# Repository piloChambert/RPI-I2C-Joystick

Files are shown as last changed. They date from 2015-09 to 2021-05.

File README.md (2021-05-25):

# RPI-I2C-Joystick

I2C Arduino based joystick for Raspberry Pi in order to be used with [RetroPie](https://github.com/RetroPie/RetroPie-Setup).
The Arduino is also used to control audio volume and power management (switch the Raspberry Pi on and off).

## Aruino

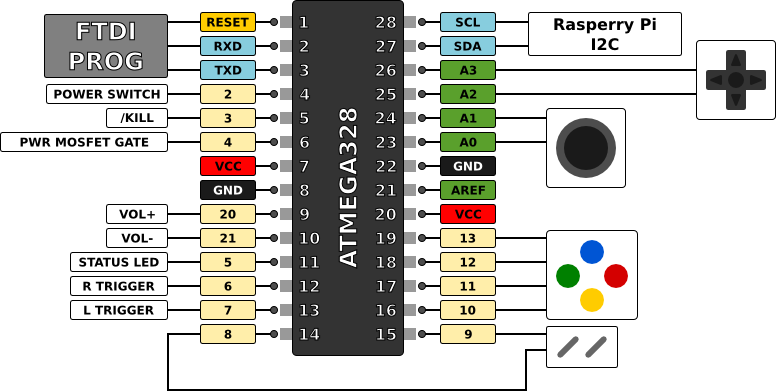
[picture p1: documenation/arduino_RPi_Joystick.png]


- The arduino (an ATMega328 running with its internal 8Mhz clock) is used to control the Raspberry Pi. It's used to read joystick buttons and analog axis. 
- The [board](https://github.com/piloChambert/RPI-I2C-Joystick/board) directory contains the schematic (and pcb), compatible with raspberry Pi GPIO. THIS IS A WORK IN PROGRESS!!! By now it's tested on a breadboard.
- The [i2c_gamepad](https://github.com/piloChambert/RPI-I2C-Joystick/i2c_gamepad) directory contains the actual arduino code. 

### hardware

The [hardware](https://github.com/piloChambert/RPI-I2C-Joystick/tree/master/hardware) directory contains the definition for the ATMega328 without quartz configuration (and PINB6 and PINB7 enable).

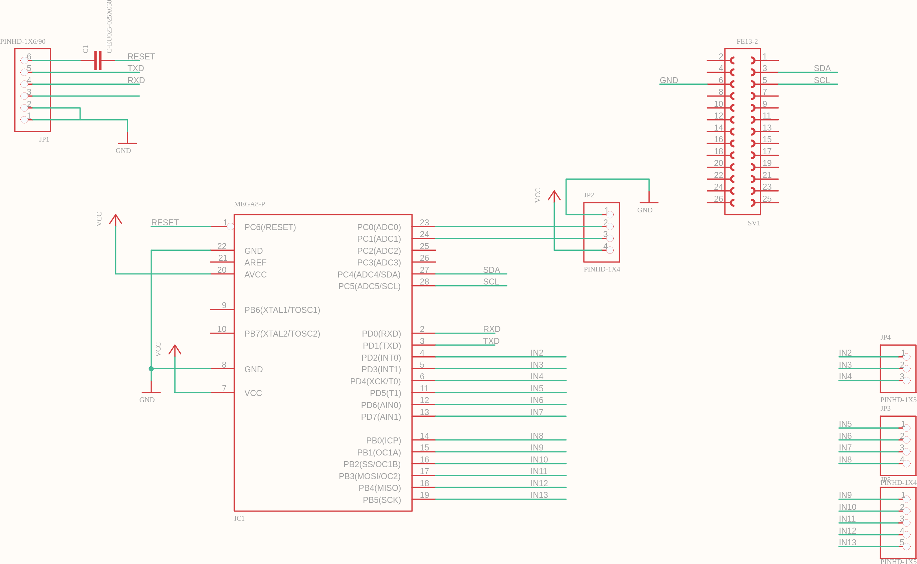
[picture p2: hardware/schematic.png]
schematic

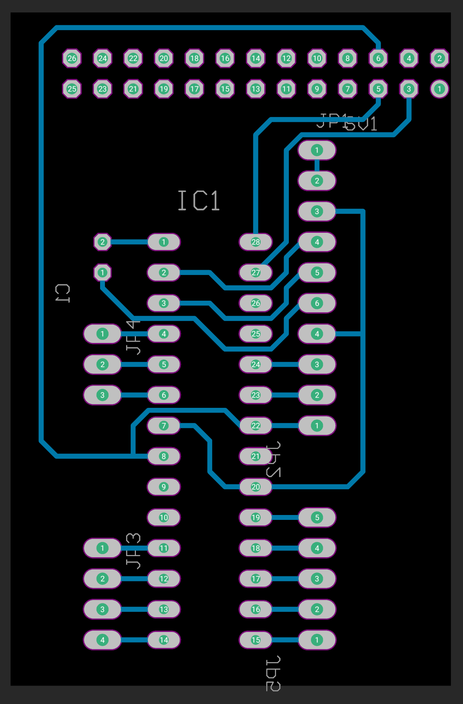
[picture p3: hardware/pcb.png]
pcb


## Raspberry Pi

### power

In order to know when the raspberry pi has been shutdown, the gpio-poweroff overlay is used. This is the /kill signal going to the arduino (HIGH when the raspberry pi is halted).

In /boot/config.txt:
```
dtoverlay=gpio-poweroff,gpiopin=4,active_low="y"
```

### joystick

The [driver](https://github.com/piloChambert/RPI-I2C-Joystick/driver) directory contains the code of the user space uinput driver for the arduino I2C joystick.

### Display Configuration

I use a 4.3" 480x272 TFT display using composite video (maybe the worst quality possible). It would be better to use a DPI interface (with the GPIO, an HDMI to DPI converter, or a DSI to DPI converter).

Here's my video and overscan settings in `/boot/config.txt`
```
disable_overscan=1

overscan_left=34
overscan_right=20
overscan_top=16
overscan_bottom=20
overscan_scale=1

# set the frame buffer to match the tft resolution
framebuffer_width=480
framebuffer_height=272
framebuffer_depth=24

# use PAL, it seems way better than NTSC!!
sdtv_mode=2

# 16:9 aspect
sdtv_aspect=3

```

In order to setup the overscan settings, I used https://github.com/popcornmix/set_overscan, and then tweaked the values by hand.

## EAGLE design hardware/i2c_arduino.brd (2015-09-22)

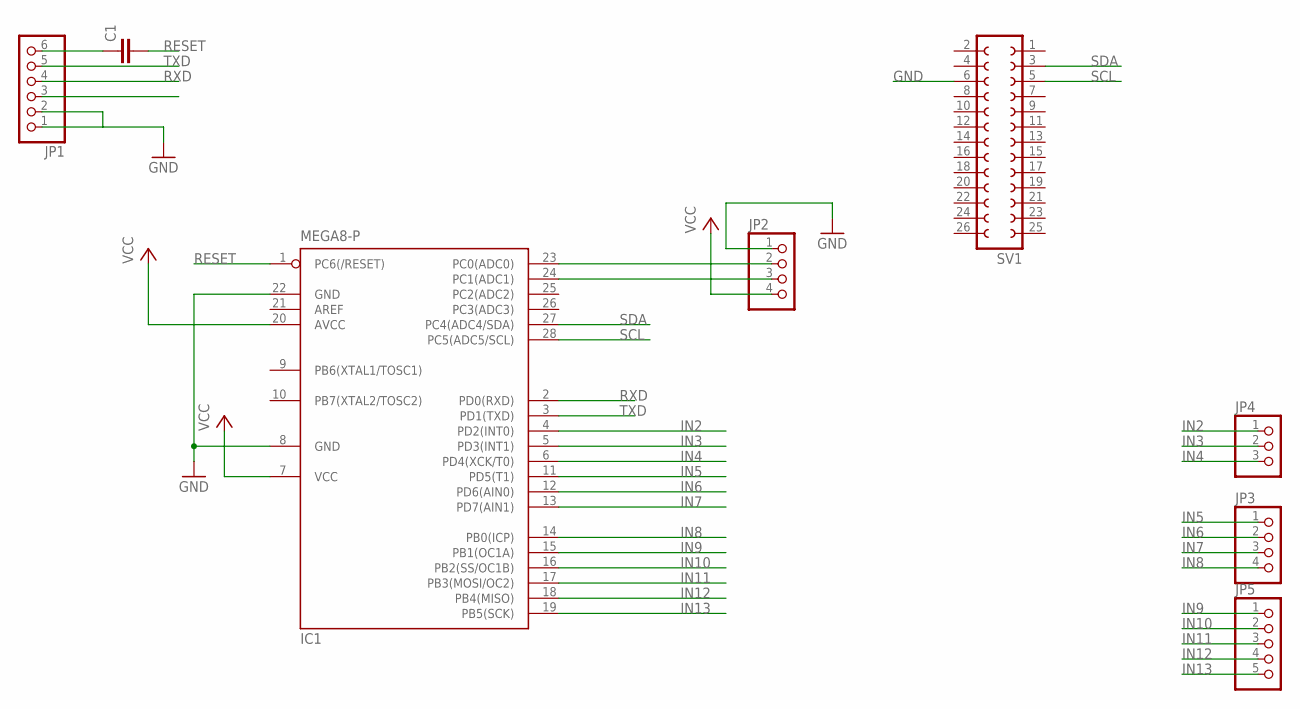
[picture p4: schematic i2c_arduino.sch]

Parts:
C1: C-EU025-025X050; C025-025X050
IC1: MEGA8-P; DIL28-3
JP1: PINHD-1X6/90; 1X06/90
JP2, JP3: PINHD-1X4; 1X04
JP4: PINHD-1X3; 1X03
JP5: PINHD-1X5; 1X05
SV1: FE13-2

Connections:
GND: IC1.8 (GND), IC1.22 (GND), JP1.1, JP1.2, JP2.1, SV1.6
IN2: IC1.4 (PD2(INT0)), JP4.1
IN3: IC1.5 (PD3(INT1)), JP4.2
IN4: IC1.6 (PD4(XCK/T0)), JP4.3
IN5: IC1.11 (PD5(T1)), JP3.1
IN6: IC1.12 (PD6(AIN0)), JP3.2
IN7: IC1.13 (PD7(AIN1)), JP3.3
IN8: IC1.14 (PB0(ICP)), JP3.4
IN9: IC1.15 (PB1(OC1A)), JP5.1
IN10: IC1.16 (PB2(SS/OC1B)), JP5.2
IN11: IC1.17 (PB3(MOSI/OC2)), JP5.3
IN12: IC1.18 (PB4(MISO)), JP5.4
IN13: IC1.19 (PB5(SCK)), JP5.5
unnamed: C1.1, JP1.6
unnamed: IC1.23 (PC0(ADC0)), JP2.2
unnamed: IC1.24 (PC1(ADC1)), JP2.3
RESET: C1.2, IC1.1 (PC6(/RESET))
RXD: IC1.2 (PD0(RXD)), JP1.4
SCL: IC1.28 (PC5(ADC5/SCL)), SV1.5
SDA: IC1.27 (PC4(ADC4/SDA)), SV1.3
TXD: IC1.3 (PD1(TXD)), JP1.5
VCC: IC1.7 (VCC), IC1.20 (AVCC), JP1.3, JP2.4

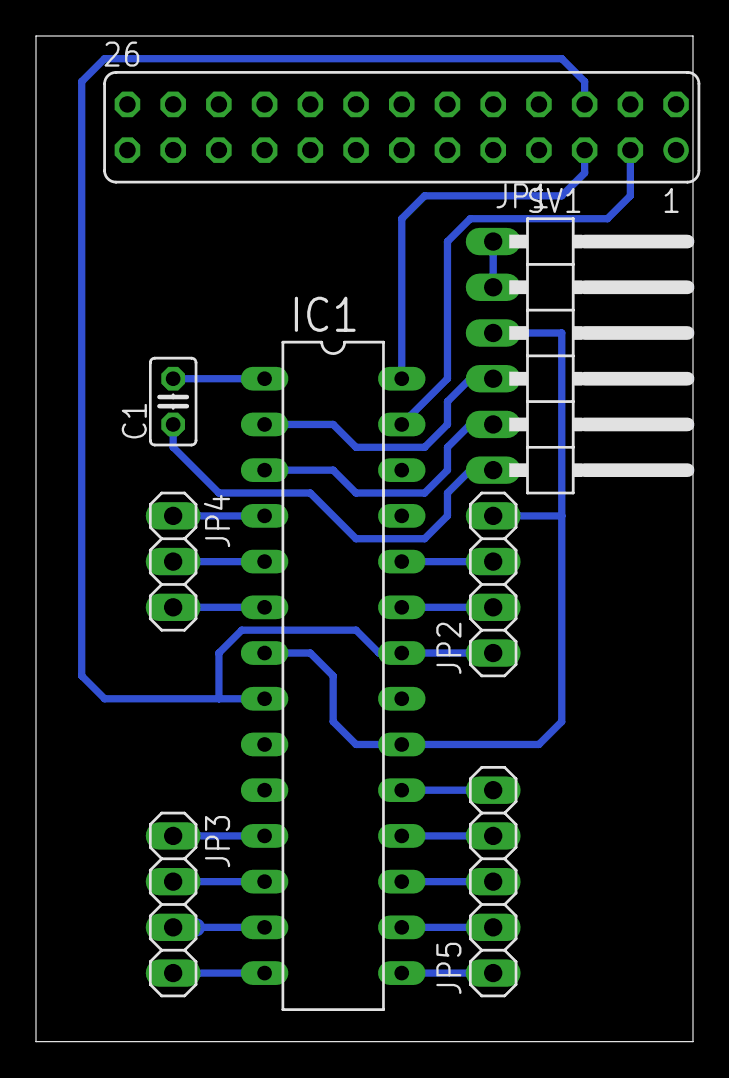
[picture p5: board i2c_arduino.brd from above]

Board: 2 copper layers, 36.5 x 55.9 mm, 8 parts (0 on the bottom side), 22 nets.

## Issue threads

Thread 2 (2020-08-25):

Question about I2C driver for this joystick

AlexShi23, 2020-08-25:
Hi, I wanted to assembly joystick according to your project. I'm having a problem with the driver. It compiled, but the device is still not available. Maybe I did something wrong, help me figure it out please.

piloChambert, 2020-08-26:
Hi!
Of course I can help :)

Did you check that the I2C is working on the raspberry?
https://learn.adafruit.com/adafruits-raspberry-pi-lesson-4-gpio-setup/configuring-i2c : with i2cdetect you should see the arduino at address 0x18.

It's an old project, so there might be some bugs (and I never finish the power switch stuff).

AlexShi23, 2020-08-26:
OK, device in Retropie appears at 0x18. Next, I copy the folder with the driver files to the Raspberry / home folder, then the make command and then I don’t know what to do.

piloChambert, 2020-08-26:
The program run i2c-joystick-driver should poll the arduino for input event, and then to a an emulated input device.
So when you run it, a new joystick should appear on your system.
To start it in background mode just run `./i2c-joystick-driver &` from the source directory.

But I think it should be used as a daemon to start it automatically with the system.

Which distribution are you using?
You can try to run `jstest /dev/input/js0` while i2c-joystick-driver to see if the different buttons are working.

AlexShi23, 2020-09-02:
Hi
I added ./i2c-joystick-driver & to startup and the system detected one game device. I use Retropie 4.5. But the joystick buttons are not pressed. The I2C device is discovered at address 0x18, but the device at address 0x68 is also detected. jstest /dev/input/js0 does not detect keystrokes. System shutdown often occur spontaneously. If turn off the Atmega328 or change the address, spontaneous shutdown disappears.
I am not good at programming code, so all hope is for your advice.

piloChambert, 2020-09-03:
Hi!
When you said "but the device at address 0x68 is also detected", is it still detected when the arduino is powered off? (it might be another I2C device inside your computer at address 0x68).

And how did you wire the button on the arduino?

To prevent the system shutdown, you can try to change ligne 261 in i2c_gamepad.ino to
`stateFunction = runState;`

and change ligne 157 to:
`if(0) {`
(instead of `if(powerSwitchHasBeenReleased && powerSwitch.state == LOW && millis() - powerSwitchPressTime > 4000) {`)

AlexShi23, 2020-09-03:
I changed lines 157 and 261 as You recommended and the buttons worked. I will move on. Thanks for answers!

piloChambert, 2020-09-05:
Great! :)
The arduino wasn't in the right mode (it was in standby mode), and that's why it wasn't working as expected. I might change that and push a fix.

I'm wondering in what kind of project you are using it? Is it for a portable pi console?

AlexShi23, 2020-09-06:
Yes. Raspberry CM3 based portable console. LCD 4.3" DPI mode.

AlexShi23, 2020-09-08:
Hi
I don’t understand how the hat is connected. How to convert a hat from analog to digital buttons? I am not using volume control and these pins are free.

piloChambert, 2020-09-09:
Seems like a very interesting project :)
Did you make a custom PCB for the compute module? That's what I wanted to do, but I never took time to finish my prototype back then! DPI screen is a really nice feature! Will you make it a public project?

For the "analog" hat wiring, I was using a voltage divider (0, 2.5v, 5v) for hat axis. But I just push a commit which should allow you to use digital pin instead for the hat (pin 20, 21, 16, 17, look lines 58 to 61) and disable volume control (and power management too).

At the top of the ino file I added compilation  configuration:
`#define USE_VOLUME_BUTTON 0`
`#define USE_ANALOG_HAT 0`
`#define USE_POWER_FUNCTION 0`

You can leave all of them to 0 in your case.

AlexShi23, 2020-09-09:
Hi
Thanks for your responsiveness.
At the moment this is a prototyping board. From the interesting will be the use of the ALC5628 DAC. I've spent some time studying it. DPI mode will occupy the entire GPIO Bank0.
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

This will be a public project, but maybe I'll be making kits for sale.

AlexShi23, 2020-09-09:
Up, down, left, right buttons are not defined by the system. I think the reason is in the driver, there they are not declared anywhere.

piloChambert, 2020-09-10:
Hey!
You're welcome! I wrote this I2C joystick driver a while ago, and never really finish the project... so I'm happy to know it could be useful to someone else :)
A DAC for audio is a really nice feature! I wanted to use a TDA1543 (hard to find the I2S one).

And you were right, the dpad event wasn't handle in the driver code! I just fixed it, and a push a new commit.
I couldn't test it, so I hope it works.
In linux DPad can be handle as button events or analog axis (xbox 360 gamepad for example generate axis event), so I added a compile option in i2c-joystick-driver.c (line 12, `#define USE_ANALOG_DPAD 0`) to use either one mode or the other.
Set it to 0 and it will generate button event (which I think should be fine for retropie)

AlexShi23, 2020-09-10:
Hi
The file JoystickDevice.c also needed to be fixed. I did it myself. Everything is working! Thanks! I'll keep you up to date.

piloChambert, 2020-09-11:
Oh, did I forgot to register DPAD_BTN_*?
`ret |= ioctl(fd, UI_SET_KEYBIT, BTN_DPAD_UP);`
`ret |= ioctl(fd, UI_SET_KEYBIT, BTN_DPAD_DOWN);`
`ret |= ioctl(fd, UI_SET_KEYBIT, BTN_DPAD_LEFT);`
`ret |= ioctl(fd, UI_SET_KEYBIT, BTN_DPAD_RIGHT);`

If you want to make a merge request I'll accept it ;) (or I can fix it with a commit).

I'd love to be updated on your project! :) Thank you!

crom4, 2020-11-18:
Hi! Thanks for the help! I never wrote but I was trying to finish this project but i had the same doubts as the other user. I'll prove what you said.

What and how is the use of the pwr mosfet gate pin? Thank you!

piloChambert, 2020-11-19:
Hey!
You're welcome! I should provide more information for the arduino code.

The power mosfet pin should be used to power on and off the raspberry pi. I can't remember if I tested or implemented it yet.
I wanted to make the arduino able to manage raspberry pi power state, but there may be other way of doing this now?

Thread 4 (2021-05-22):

Hardware Images

konsumer, 2021-05-22:
Great project!

I like to see schematic/PCB without loading it up into a viewer. It can be really nice just right in the README file. If you are interested, I can PR for these in README:

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

piloChambert, 2021-05-23:
Thank you!

And yes you can make a PR, and I'll merge it.
I didn't know about altium, it's a nice and handy tool!

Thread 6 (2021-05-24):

Question: serial comm

konsumer, 2021-05-24:
Hi,
I like the design of the board, but I was thinking I could free up 2 more IO pins from arduino if I used the RX/TX instead of i2c to talk to pi, and this would also allow me to write the "firmware" from pi, and allow other styles of firmware like [firmata](https://www.arduino.cc/en/reference/firmata) (keep logic in the driver, and the Arduino is just used for it's GPIO.) Do you have any opinions on this? Am I wrong about this as an alternative?

konsumer, 2021-05-24:
It seems like it might also allow something like [this](https://github.com/mcgurk/Linux-Arduino-Serial-Joystick).

piloChambert, 2021-05-25:
Using the serial port is actually a very smart idea !
I feel stupid to not thought about it when doing the I2C.

The Linux-Arduino-Serial-Joystick project seems to do this?

konsumer, 2021-05-25:
I was originally looking for i2c, and it helped my find this project. I think both are good, depending on what you're doing (if I were doing a bunch of i2c, I could have them share the 2 pins, saving the serial for something else.) Also, I'm not sure if serial timing is ok without a XTAL. I'll do some tests and report back. It may make sense to have both options.

konsumer, 2021-05-25:
I made [this](https://github.com/notnullgames/arduinojoystick) for initial ideas, but I still need to do a lot of testing.

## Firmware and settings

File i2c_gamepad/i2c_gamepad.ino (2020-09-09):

#include <Wire.h>
#include <avr/sleep.h>

// ------------------------------------------
// Options
// ------------------------------------------
#define USE_VOLUME_BUTTON 0
#define USE_ANALOG_HAT 0 // USE_VOLUME_BUTTON should be 0 in order to use USE_ANALOG_HAT = 0
#define USE_POWER_FUNCTION 0

// ------------------------------------------
// Configuration
// ------------------------------------------
#define I2C_ADDRESS 0x18
#define SWITCH_DEBOUNCE_TIME 50 // ms
#define ANALOG_PIN_X 0
#define ANALOG_PIN_Y 1
#define HAT_PIN_X 2
#define HAT_PIN_Y 3
#define POWER_LED_PIN 5
#define POWER_SWITCH_PIN 2
#define POWER_MOSFET_GATE 4
#define PI_KILL_PIN 3

// switch type definition
#define BTN_A           0x00
#define BTN_B           0x01
#define BTN_X           0x02
#define BTN_Y           0x03
#define BTN_LT          0x04
#define BTN_RT          0x05
#define BTN_START       0x06
#define BTN_SELECT      0x07
#define BTN_UP          0x08
#define BTN_DOWN        0x09
#define BTN_LEFT        0x0A
#define BTN_RIGHT       0x0B
#define BTN_DUMMY       0xFF

struct InputSwitch {
  unsigned char pin;
  unsigned char state;
  unsigned long time;
  unsigned char code;
};

// the 8 switches 
InputSwitch switches[] = {
  {13, HIGH, 0, BTN_A},
  {12, HIGH, 0, BTN_B},
  {11, HIGH, 0, BTN_X},
  {10, HIGH, 0, BTN_Y},
  {7, HIGH, 0, BTN_LT},
  {6, HIGH, 0, BTN_RT},
  {8, HIGH, 0, BTN_START},
  {9, HIGH, 0, BTN_SELECT},
#if USE_ANALOG_HAT == 0
  {20, HIGH, 0, BTN_UP},
  {21, HIGH, 0, BTN_DOWN},
  {16, HIGH, 0, BTN_LEFT},
  {17, HIGH, 0, BTN_RIGHT},
#endif
};

// force analog hat if using volume button
#if USE_VOLUME_BUTTON == 1
#define USE_ANALOG_HAT 1
#endif

// return true if switch state has changed!
bool updateSwitch(struct InputSwitch *sw) {
  int newState = digitalRead(sw->pin);

  if(newState != sw->state && millis() - sw->time > SWITCH_DEBOUNCE_TIME) {
    // change state!
    sw->state = newState;

    // record last update
    sw->time = millis();
    
    return true;
  }

  // else 
  return false;
}

// I2C data definition
struct I2CJoystickStatus {
  uint16_t buttons; // button status
  uint8_t axis0; // first axis
  uint8_t axis1; // second axis
  uint8_t powerDownRequest; // when true, request the pi to shutdown
  uint8_t audioVolume;
};

I2CJoystickStatus joystickStatus;

InputSwitch powerSwitch = {POWER_SWITCH_PIN, HIGH, 0, 0};
unsigned long powerSwitchPressTime = 0;
bool powerSwitchHasBeenReleased = true; // a flag used to know if the power switch has been released since last state change

unsigned long ledBlinkTimer = 0;
int powerLedStatus = LOW;

#if USE_VOLUME_BUTTON == 1
InputSwitch volPlusSwitch = {20, HIGH, 0, BTN_DUMMY};
InputSwitch volMinusSwitch = {21, HIGH, 0, BTN_DUMMY};
#endif

void (*stateFunction)(void);
unsigned long wakeUpTime = 0;

void startupState() {
  // blink led
  if(millis() - ledBlinkTimer > 500) {
    powerLedStatus = powerLedStatus == HIGH ? LOW : HIGH;
    
    digitalWrite(POWER_LED_PIN, powerLedStatus);
    ledBlinkTimer = millis();
  }
  
  // update power switch
  if(updateSwitch(&powerSwitch)) {
    if(powerSwitch.state == LOW) {
      Serial.println("Pressed");
      powerSwitchPressTime = millis();
    } else {
      powerSwitchHasBeenReleased = true;
    }
  }

  if(powerSwitch.state == LOW) {
    // reset sleep timer
    wakeUpTime = millis();

    // if pressing power for more the 3s, change state
    if(millis() - powerSwitchPressTime > 3000) {
      // go to run state
      stateFunction = runState;

      // reset release flag
      powerSwitchHasBeenReleased = false;
    
      // led is on
      powerLedStatus = HIGH;
      digitalWrite(POWER_LED_PIN, powerLedStatus);

      // power the pi
      digitalWrite(POWER_MOSFET_GATE, LOW);      

      Serial.println("Starting up the pi!");
    }
  }

  // if still in this state after 5s, go to sleep
  if(millis() - wakeUpTime > 5000 && powerSwitch.state == HIGH) {
    Serial.println("Go to sleep");
    delay(1000);
    sleepNow();
  }
}

void runState() {
#if USE_POWER_FUNCTION == 1
  // update power switch
  if(updateSwitch(&powerSwitch)) {
    if(powerSwitch.state == LOW) {
      Serial.println("Pressed");
      powerSwitchPressTime = millis();
    } else {
      powerSwitchHasBeenReleased = true;
    }
  }

  // if the switch has been released since we are in this state
  // if it's pressed and pressed for more than 4s, then change state
  if(powerSwitchHasBeenReleased && powerSwitch.state == LOW && millis() - powerSwitchPressTime > 4000) {
    // go to halt state
    stateFunction = haltState;

    // reset power switch timer to highest value
    powerSwitchHasBeenReleased = false;

    // stoping the pi
    joystickStatus.powerDownRequest = 1;

    Serial.println("Stoping the pi!");
  }
#endif

  // update switch etc
  scanAnalog();
  scanInput();
}

void haltState() {
  // blink status led
  if(millis() - ledBlinkTimer > 100) {
    if(powerLedStatus == LOW) {
      powerLedStatus = HIGH;
    } else {
      powerLedStatus = LOW;
    }

    digitalWrite(POWER_LED_PIN, powerLedStatus);
    ledBlinkTimer = millis();
  }  

  // wait for pi kill signal
  if(digitalRead(PI_KILL_PIN) == LOW) {
    // shut down the power
    digitalWrite(POWER_MOSFET_GATE, HIGH);

    // go back to start state
    stateFunction = startupState;
  }
}

void pinInterrupt(void) {
  detachInterrupt(0);
}

void sleepNow() {
  // Set sleep enable (SE) bit:
  sleep_enable();
  
  attachInterrupt(0, pinInterrupt, LOW);
  
  // Choose our preferred sleep mode:
  set_sleep_mode(SLEEP_MODE_PWR_DOWN);

  // turn led off
  digitalWrite(POWER_LED_PIN, LOW);
 
  // Put the device to sleep:
  sleep_mode();
 
  // Upon waking up, sketch continues from this point.
  sleep_disable();

  wakeUpTime = millis();
  delay(1000);
  Serial.println("Awake!!");
}

void setup()
{
  Wire.begin(I2C_ADDRESS);      // join i2c bus 
  Wire.onRequest(requestEvent); // register event

  // prints title with ending line break
  Serial.begin(9600);
  while (!Serial) {
    ; // wait for serial port to connect. Needed for Leonardo only
  }
  Serial.println("I2C Gamepad controller");

  // default status
  joystickStatus.buttons = 0;
  joystickStatus.axis0 = 127;
  joystickStatus.axis1 = 127;
  joystickStatus.powerDownRequest = 0;
  joystickStatus.audioVolume = 100;
  
  // pin configuration
  for(int i = 0; i < sizeof(switches) / sizeof(InputSwitch); i++) {
    pinMode(switches[i].pin, INPUT_PULLUP);
  }

  pinMode(POWER_LED_PIN, OUTPUT);
  digitalWrite(POWER_LED_PIN, HIGH);

  pinMode(POWER_SWITCH_PIN, INPUT_PULLUP);
  pinMode(PI_KILL_PIN, INPUT_PULLUP);

#if USE_VOLUME_BUTTON == 1
  pinMode(volPlusSwitch.pin, INPUT_PULLUP);
  pinMode(volMinusSwitch.pin, INPUT_PULLUP);
#endif

  pinMode(POWER_MOSFET_GATE, OUTPUT);

  // switch to startup state
#if USE_POWER_FUNCTION == 1
  stateFunction = startupState;
#else
  stateFunction = runState;
#endif

  // turn led on
  powerLedStatus = HIGH;
  ledBlinkTimer = millis();
  digitalWrite(POWER_LED_PIN, powerLedStatus);
}

void scanInput() {
  for(int i = 0; i < sizeof(switches) / sizeof(InputSwitch); i++) {
    if(updateSwitch(&switches[i])) {
      if(switches[i].state == HIGH) // button released
        joystickStatus.buttons &= ~(1 << switches[i].code);
      else // button pressed
        joystickStatus.buttons |= (1 << switches[i].code);
    }
  }

  static uint16_t oldButtons = 0;
  if(joystickStatus.buttons != oldButtons) {
    Serial.println(joystickStatus.buttons);
    oldButtons = joystickStatus.buttons;
  }

#if USE_VOLUME_BUTTON == 1
  // volume
  if(updateSwitch(&volPlusSwitch) && volPlusSwitch.state == LOW) {
    joystickStatus.audioVolume = min(joystickStatus.audioVolume + 5, 100); 
  }

  if(updateSwitch(&volMinusSwitch) && volMinusSwitch.state == LOW) {
    joystickStatus.audioVolume = max(joystickStatus.audioVolume - 5, 0); 
  }
#endif
}

void scanAnalog() {
  // read analog stick values
  int x = analogRead(ANALOG_PIN_X);
  int y = analogRead(ANALOG_PIN_Y);

  // translate into a valid range
  x = min(max(((x - 240) / 10), 0) << 2, 255);
  y = min(max(((y - 200) / 10), 0) << 2, 255);

  // store them in the I2C data
  joystickStatus.axis0 = x;
  joystickStatus.axis1 = y;

  // read hat values
#if USE_ANALOG_HAT == 1
  int hatx = analogRead(HAT_PIN_X);
  if(hatx > 300 && hatx < 400)
    joystickStatus.buttons |= (1 << BTN_LEFT);
  else
    joystickStatus.buttons &= ~(1 << BTN_LEFT);

  if(hatx > 950)
    joystickStatus.buttons |= (1 << BTN_RIGHT);
  else
    joystickStatus.buttons &= ~(1 << BTN_RIGHT);
  
  int haty = analogRead(HAT_PIN_Y);
  if(haty > 300 && haty < 400)
    joystickStatus.buttons |= (1 << BTN_UP);
  else
    joystickStatus.buttons &= ~(1 << BTN_UP);

  if(haty > 950)
    joystickStatus.buttons |= (1 << BTN_DOWN);
  else
    joystickStatus.buttons &= ~(1 << BTN_DOWN);

  /*
  Serial.print("x : "); Serial.print(hatx);
  Serial.print("y : "); Serial.print(haty);
  Serial.println("");*/
#endif
}

void loop() {
  // execute state function
  stateFunction();
  delay(10);
}

// function that executes whenever data is requested by master
// this function is registered as an event, see setup()
void requestEvent() {
  Wire.write((char *)&joystickStatus, sizeof(I2CJoystickStatus)); 
}

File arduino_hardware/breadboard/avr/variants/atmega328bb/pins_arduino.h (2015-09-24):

/*
  pins_arduino.h - Pin definition functions for Arduino
  Part of Arduino - http://www.arduino.cc/

  Copyright (c) 2007 David A. Mellis

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
  $Id: wiring.h 249 2007-02-03 16:52:51Z mellis $
*/

#ifndef Pins_Arduino_h
#define Pins_Arduino_h

#include <avr/pgmspace.h>

#define NUM_DIGITAL_PINS            22
#define NUM_ANALOG_INPUTS           6
#define analogInputToDigitalPin(p)  ((p < 6) ? (p) + 14 : -1)

#if defined(__AVR_ATmega8__)
#define digitalPinHasPWM(p)         ((p) == 9 || (p) == 10 || (p) == 11)
#else
#define digitalPinHasPWM(p)         ((p) == 3 || (p) == 5 || (p) == 6 || (p) == 9 || (p) == 10 || (p) == 11)
#endif

static const uint8_t SS   = 10;
static const uint8_t MOSI = 11;
static const uint8_t MISO = 12;
static const uint8_t SCK  = 13;

static const uint8_t SDA = 18;
static const uint8_t SCL = 19;
#define LED_BUILTIN 13

static const uint8_t A0 = 14;
static const uint8_t A1 = 15;
static const uint8_t A2 = 16;
static const uint8_t A3 = 17;
static const uint8_t A4 = 18;
static const uint8_t A5 = 19;
static const uint8_t A6 = 20;
static const uint8_t A7 = 21;

#define digitalPinToPCICR(p)    (((p) >= 0 && (p) <= 21) ? (&PCICR) : ((uint8_t *)0))
#define digitalPinToPCICRbit(p) (((p) <= 7) ? 2 : (((p) <= 13) ? 0 : 1))
#define digitalPinToPCMSK(p)    (((p) <= 7) ? (&PCMSK2) : (((p) <= 13) ? (&PCMSK0) : (((p) <= 21) ? (&PCMSK1) : ((uint8_t *)0))))
#define digitalPinToPCMSKbit(p) (((p) <= 7) ? (p) : (((p) <= 13) ? ((p) - 8) : ((p) - 14)))

#define digitalPinToInterrupt(p)  ((p) == 2 ? 0 : ((p) == 3 ? 1 : NOT_AN_INTERRUPT))

#ifdef ARDUINO_MAIN

// On the Arduino board, digital pins are also used
// for the analog output (software PWM).  Analog input
// pins are a separate set.

// ATMEL ATMEGA8 & 168 / ARDUINO
//
//                  +-\/-+
//            PC6  1|    |28  PC5 (AI 5)
//      (D 0) PD0  2|    |27  PC4 (AI 4)
//      (D 1) PD1  3|    |26  PC3 (AI 3)
//      (D 2) PD2  4|    |25  PC2 (AI 2)
// PWM+ (D 3) PD3  5|    |24  PC1 (AI 1)
//      (D 4) PD4  6|    |23  PC0 (AI 0)
//            VCC  7|    |22  GND
//            GND  8|    |21  AREF
//            PB6  9|    |20  AVCC
//            PB7 10|    |19  PB5 (D 13)
// PWM+ (D 5) PD5 11|    |18  PB4 (D 12)
// PWM+ (D 6) PD6 12|    |17  PB3 (D 11) PWM
//      (D 7) PD7 13|    |16  PB2 (D 10) PWM
//      (D 8) PB0 14|    |15  PB1 (D 9) PWM
//                  +----+
//
// (PWM+ indicates the additional PWM pins on the ATmega168.)

// ATMEL ATMEGA1280 / ARDUINO
//
// 0-7 PE0-PE7   works
// 8-13 PB0-PB5  works
// 14-21 PA0-PA7 works 
// 22-29 PH0-PH7 works
// 30-35 PG5-PG0 works
// 36-43 PC7-PC0 works
// 44-51 PJ7-PJ0 works
// 52-59 PL7-PL0 works
// 60-67 PD7-PD0 works
// A0-A7 PF0-PF7
// A8-A15 PK0-PK7


// these arrays map port names (e.g. port B) to the
// appropriate addresses for various functions (e.g. reading
// and writing)
const uint16_t PROGMEM port_to_mode_PGM[] = {
	NOT_A_PORT,
	NOT_A_PORT,
	(uint16_t) &DDRB,
	(uint16_t) &DDRC,
	(uint16_t) &DDRD,
};

const uint16_t PROGMEM port_to_output_PGM[] = {
	NOT_A_PORT,
	NOT_A_PORT,
	(uint16_t) &PORTB,
	(uint16_t) &PORTC,
	(uint16_t) &PORTD,
};

const uint16_t PROGMEM port_to_input_PGM[] = {
	NOT_A_PORT,
	NOT_A_PORT,
	(uint16_t) &PINB,
	(uint16_t) &PINC,
	(uint16_t) &PIND,
};

const uint8_t PROGMEM digital_pin_to_port_PGM[] = {
	PD, /* 0 */
	PD,
	PD,
	PD,
	PD,
	PD,
	PD,
	PD,
	PB, /* 8 */
	PB,
	PB,
	PB,
	PB,
	PB,
	PC, /* 14 */
	PC,
	PC,
	PC,
	PC,
	PC,
	PB, /* extra */
	PB
};

const uint8_t PROGMEM digital_pin_to_bit_mask_PGM[] = {
	_BV(0), /* 0, port D */
	_BV(1),
	_BV(2),
	_BV(3),
	_BV(4),
	_BV(5),
	_BV(6),
	_BV(7),
	_BV(0), /* 8, port B */
	_BV(1),
	_BV(2),
	_BV(3),
	_BV(4),
	_BV(5),
	_BV(0), /* 14, port C */
	_BV(1),
	_BV(2),
	_BV(3),
	_BV(4),
	_BV(5),
	_BV(6), /* extra, port B */
	_BV(7),
};

const uint8_t PROGMEM digital_pin_to_timer_PGM[] = {
	NOT_ON_TIMER, /* 0 - port D */
	NOT_ON_TIMER,
	NOT_ON_TIMER,
	// on the ATmega168, digital pin 3 has hardware pwm
#if defined(__AVR_ATmega8__)
	NOT_ON_TIMER,
#else
	TIMER2B,
#endif
	NOT_ON_TIMER,
	// on the ATmega168, digital pins 5 and 6 have hardware pwm
#if defined(__AVR_ATmega8__)
	NOT_ON_TIMER,
	NOT_ON_TIMER,
#else
	TIMER0B,
	TIMER0A,
#endif
	NOT_ON_TIMER,
	NOT_ON_TIMER, /* 8 - port B */
	TIMER1A,
	TIMER1B,
#if defined(__AVR_ATmega8__)
	TIMER2,
#else
	TIMER2A,
#endif
	NOT_ON_TIMER,
	NOT_ON_TIMER,
	NOT_ON_TIMER,
	NOT_ON_TIMER, /* 14 - port C */
	NOT_ON_TIMER,
	NOT_ON_TIMER,
	NOT_ON_TIMER,
	NOT_ON_TIMER,
};

#endif
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

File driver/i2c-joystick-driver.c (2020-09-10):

// http://elinux.org/Interfacing_with_I2C_Devices

#include <stdio.h>
#include <stdlib.h>

#include "I2C.h"
#include "JoystickDevice.h"

#define I2C_GAMEPAD_ADDRESS 0x18
#define UPDATE_FREQ 5000 // ms (200Hz)

#define USE_ANALOG_DPAD 0 // use ABS_HAT0X and ABS_HAT0Y instead of BTN_DPAD_* events

typedef struct {
  uint16_t buttons; // button status
  uint8_t axis0; // first axis
  uint8_t axis1; // second axis
  uint8_t powerDownRequest; // when true, request the pi to shutdown
  uint8_t audioVolume;
} I2CJoystickStatus;

int readI2CJoystick(int file, I2CJoystickStatus *status) {
  int s = readI2CSlave(file, I2C_GAMEPAD_ADDRESS, status, sizeof(I2CJoystickStatus));
  if(s != sizeof(I2CJoystickStatus))
    return -1; // error

  return 0; // no error
}

#define TestBitAndSendKeyEvent(oldValue, newValue, bit, event) if((oldValue & (1 << bit)) != (newValue & (1 << bit))) sendInputEvent(UInputFIle, EV_KEY, event, (newValue & (1 << bit)) == 0 ? 0 : 1);

void updateUInputDevice(int UInputFIle, I2CJoystickStatus *newStatus, I2CJoystickStatus *status) {
  // update button event
  TestBitAndSendKeyEvent(status->buttons, newStatus->buttons, 0x00, BTN_A);
  TestBitAndSendKeyEvent(status->buttons, newStatus->buttons, 0x01, BTN_B);
  TestBitAndSendKeyEvent(status->buttons, newStatus->buttons, 0x02, BTN_X);
  TestBitAndSendKeyEvent(status->buttons, newStatus->buttons, 0x03, BTN_Y);
  TestBitAndSendKeyEvent(status->buttons, newStatus->buttons, 0x04, BTN_TL);
  TestBitAndSendKeyEvent(status->buttons, newStatus->buttons, 0x05, BTN_TR);
  TestBitAndSendKeyEvent(status->buttons, newStatus->buttons, 0x06, BTN_START);
  TestBitAndSendKeyEvent(status->buttons, newStatus->buttons, 0x07, BTN_SELECT);

#if USE_ANALOG_DPAD == 0
  TestBitAndSendKeyEvent(status->buttons, newStatus->buttons, 0x08, BTN_DPAD_UP);
  TestBitAndSendKeyEvent(status->buttons, newStatus->buttons, 0x09, BTN_DPAD_DOWN);
  TestBitAndSendKeyEvent(status->buttons, newStatus->buttons, 0x0A, BTN_DPAD_LEFT);
  TestBitAndSendKeyEvent(status->buttons, newStatus->buttons, 0x0B, BTN_DPAD_RIGHT);
#else
  // HAT0Y (up/down)
  if((status->buttons & (1 << 0x08)) != (newStatus->buttons & (1 << 0x08)) || (status->buttons & (1 << 0x09)) != (newStatus->buttons & (1 << 0x09))) {
    int32_t val = (newValue & (1 << 0x08)) != 0 ? -1 : ((newValue & (1 << 0x09)) != 0 ? 1 : 0);
    sendInputEvent(UInputFIle, EV_ABS, ABS_HAT0Y, val);  
  }

  // HAT0X (left/right)
  if((status->buttons & (1 << 0x0A)) != (newStatus->buttons & (1 << 0x0A)) || (status->buttons & (1 << 0x0B)) != (newStatus->buttons & (1 << 0x0B))) {
    int32_t val = (newValue & (1 << 0x0A)) != 0 ? -1 : ((newValue & (1 << 0x0B)) != 0 ? 1 : 0);
    sendInputEvent(UInputFIle, EV_ABS, ABS_HAT0X, val);
  }
#endif

  // joystick axis 
  if(newStatus->axis0 != status->axis0) {
    // send event
    int val = newStatus->axis0;
    val = (val - 128) * 4;
    sendInputEvent(UInputFIle, EV_ABS, ABS_X, val);
  }

  if(newStatus->axis1 != status->axis1) {
    // send event
    int val = newStatus->axis1;
    val = (val - 128) * 4;
    sendInputEvent(UInputFIle, EV_ABS, ABS_Y, val);
  }
}

#include <alsa/asoundlib.h>
// input volume : [0..100]
// XXX maybe need some tweak!
// input value should be a dB value, not a % of the dB range
void SetAlsaMasterVolume(long volume)
{
    long min, max;
    snd_mixer_t *handle;
    snd_mixer_selem_id_t *sid;
    const char *card = "default";
    const char *selem_name = "PCM";

    snd_mixer_open(&handle, 0);
    snd_mixer_attach(handle, card);
    snd_mixer_selem_register(handle, NULL, NULL);
    snd_mixer_load(handle);

    snd_mixer_selem_id_alloca(&sid);
    snd_mixer_selem_id_set_index(sid, 0);
    snd_mixer_selem_id_set_name(sid, selem_name);
    snd_mixer_elem_t* elem = snd_mixer_find_selem(handle, sid);

    snd_mixer_selem_get_playback_volume_range(elem, &min, &max);

    float v = (float)volume * 0.01 * (float)(max - min) + min;
    snd_mixer_selem_set_playback_volume_all(elem, v);
    snd_mixer_close(handle);
}

int main(int argc, char *argv[]) {
  // open I2C device  
  int I2CFile = openI2C(1);

  // current joystick status
  I2CJoystickStatus status;
  status.buttons = 0;
  status.axis0 = 127;
  status.axis1 = 127;
  status.powerDownRequest = 0;
  status.audioVolume = -1; // so it will be set at first request

  // create uinput device
  int UInputFIle = createUInputDevice();

  printf("Driver ready\n");

  while(1) {
    // read new status from I2C
    I2CJoystickStatus newStatus;
    if(readI2CJoystick(I2CFile, &newStatus) != 0) {
      printf("can't read I2C device!\n");
    } else {
      // everything is ok
      updateUInputDevice(UInputFIle, &newStatus, &status);

      if(newStatus.powerDownRequest) {
	// halt!
	system("halt");
      }

      if(newStatus.audioVolume != status.audioVolume) {
	SetAlsaMasterVolume(newStatus.audioVolume);
      }

      status = newStatus;
    }

    // sleep until next update
    usleep(UPDATE_FREQ);
  }

  // close file
  close(I2CFile);
  ioctl(UInputFIle, UI_DEV_DESTROY);
}

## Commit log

2015-09-20 Added rpi driver
2015-09-20 added arduino project
2015-09-20 Put driver in its directory
2015-09-20 Updated RPI driver
2015-09-20 Updated arduino code to handle switch
2015-09-20 Added schematic and pcb
    [i2c_arduino.brd, i2c_arduino.sch]
2015-09-22 Updated buttons handling
    [i2c_arduino.brd, i2c_arduino.sch]
2015-09-24 Updated I2C driver, added blob with KILL signal
2015-09-25 Updated arduino code Removed blob (not used anymore)
    [i2c_arduino.brd, i2c_arduino.sch]
2015-09-25 fixed arduino code
2015-09-26 Added sleep mode test on arduino Added Arduino wiring drawing
2015-09-27 Added png version of arduino wiring
2015-09-27 Updated Arduino wiring
2015-09-27 Added shutdown with pwr switch refactorcode
2015-11-03 updated case design
2015-12-02 added case design
2015-12-31 updated case
2016-02-07 Updated arduino states
2020-09-10 Added dpad event in joystick driver

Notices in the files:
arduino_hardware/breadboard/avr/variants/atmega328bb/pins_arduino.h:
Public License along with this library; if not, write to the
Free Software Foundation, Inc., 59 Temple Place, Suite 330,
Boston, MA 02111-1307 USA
